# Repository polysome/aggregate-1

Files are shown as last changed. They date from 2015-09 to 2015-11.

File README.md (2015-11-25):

# aggregate-1

The aggregate-1 is a general purpose FPGA development platform for designs that require both a large fabric and high speed interconnect. The miniPCIe interface allows operation with most laptops, embedded SBCs and routers. It is particularly suited to security applications.

Hardware
========

• Xilinx Spartan 6 LX150T<br />
• 1GB DDR3<br />
• microSD card slot (bootable)<br />
• 128Mb write protected SPI flash<br />
• External frequency reference input for realtime applications.<br />
• Onboard 32.768KHz and 100MHz oscillators.<br />
• 38 pairs of 1.5V GPIO over two flex cable breakout headers ~ 7.6Gbps @ 200MHz.<br />
• Open source design including gerber files, manufacturing specifications, BOM and source list.<br />

Applications
============

• Libre SoC development. Bitstreams for RISC-V and OpenSPARC will be available<br />
• Hardware Security Module (HSM)<br />
• Authentication token<br />
• Verifiable encrypted storage with cascade blockciphers and isolated PIN entry<br />
• Cryptographic acceleration<br />
• Software defined radio<br />

Preorder
========

Preorders are available now at &nbsp; <a href="https://www.crowdsupply.com/polysome/aggregate-1">CrowdSupply</a>




Credits
=======

This project is a collaboration between [Numato Lab](http://numato.com) and Polysome Research. 

Anoop Jose<br />
Elijah Fedele<br />
Thom Lauret<br />

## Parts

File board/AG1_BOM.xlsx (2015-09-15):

Designator | Footprint | Value | Tolerance | Quantity | Manufacturer | Manufacturer Part Number | Description | Component Documentation | Supplier | Supplier Part Number | Price Break @500+ | Price Break @1000+ | MOQ @500 | MOQ @1000 | MOQ @500 Cost | MOQ @1000 Cost | Actual Required @ 500 | Actual Required @ 1000 | MOQ Surplus @500 | MOQ Surplus @1000 | MOQ Surplus $@500 | MOQ Surplus $@1000 | Digi-Reel Part Number | Digi-Reel Best Break @500 | Digi-Reel Best Break @1000 | Digi-Reel Cost @500 | Digi-Reel Cost @1000
C1, C2, C3, C4, C5, C6, C7, C8, C9, C10, C11, C12, C13, C14, C15, C16, C17, C18, C19, C20, C21, C22, C23, C25, C27, C66, C67, C68, C69, C70, C71, C79, C80,C92 | 0402 (1005 METRIC) | 0.1uF | 5% | 34 | Kemet | C0402C104J4RACTU | CAP CER 0.1UF 16V 5% X7R 0402 | http://www.kemet.com/Lists/ProductCatalog/Attachments/53/KEM_C1002_X7R_SMD.pdf | Digi-Key | 399-7761-2-ND | 0.084630 | 0.076440 | 20000 | 50000 | 1692.6 | 3822 | 17000 | 34000 | 3000 | 16000 | 253.89 | 1223.04 | 399-7761-6-ND | 0.103740 | 0.103740 | 1770.58 | 3534.16
C24, C26 | 0402 (1005 METRIC) | 15pF | 1% | 2 | Kemet | CBR04C150F1GAC | CAP CER 15PF 100V 1% NP0 0402 | http://www.kemet.com/Lists/ProductCatalog/Attachments/490/KEM_C1030_CBR_SMD.pdf | Digi-Key | 399-11249-2-ND | 0.142520 | 0.142520 | 10000 | 10000 | 1425.2 | 1425.2 | 1000 | 2000 | 9000 | 8000 | 1282.68 | 1140.16 | 399-11249-6-ND | 0.229050 | 0.198510 | 236.05 | 404.02
C28, C29, C30, C31, C32, C33, C38, C39, C40, C41, C42, C43, C49, C50, C51, C52, C53, C54, C59, C60, C61, C62, C84, C85, C86, C87, C88, C89 | 0402 (1005 METRIC) | 0.47uF | 10% | 28 | Kemet | C0402C474K9PACTU | CAP CER 0.47UF 6.3V 10% X5R 0402 | http://www.kemet.com/Lists/ProductCatalog/Attachments/19/KEM_C1006_X5R_SMD.pdf | Digi-Key | 399-4899-2-ND | 0.016150 | 0.015300 | 20000 | 30000 | 323 | 459 | 14000 | 28000 | 6000 | 2000 | 96.9 | 30.6 | 399-4899-6-ND | 0.019760 | 0.019760 | 283.64 | 560.28
C34, C35, C44, C45, C46, C55, C56, C63, C64 | 0603 (1608 METRIC) | 4.7uF | 10% | 9 | Kemet | C0603C475K9PACTU | CAP CER 4.7UF 6.3% 10% X5R 0603 | http://www.kemet.com/Lists/ProductCatalog/Attachments/19/KEM_C1006_X5R_SMD.pdf | Digi-Key | 399-3482-2-ND | 0.018000 | 0.017100 | 8000 | 12000 | 144 | 205.2 | 4500 | 9000 | 3500 | 3000 | 63 | 51.3 | 399-3482-6-ND | 0.024750 | 0.024750 | 118.375 | 229.75
C36, C37, C47, C48, C58 | 0603 (1608 METRIC) | 100uF | 20% | 5 | AVX | F980G107MMA | CAP TANT 100UF 4V 20% 0603 | http://www.avx.com/docs/Catalogs/f98.pdf | Digi-Key | F980G107MMAAVX-ND | 0.408240 | 0.408240 | 4000 | 8000 | 1632.96 | 3265.92 | 2500 | 5000 | 1500 | 3000 | 612.36 | 1224.72 | - |  |  | 2507 | 5007
C57 | 0603 (1608 METRIC) | 47uF | 20% | 1 | AVX | F980J476MMA | CAP TANT 47UF 6.3V 20% 0603 | http://www.avx.com/docs/Catalogs/f98.pdf | Digi-Key | 478-8644-2-ND | 0.185700 | 0.185700 | 4000 | 4000 | 742.8 | 742.8 | 500 | 1000 | 3500 | 3000 | 649.95 | 557.1 | 478-8644-6-ND | 0.303320 | 0.278550 | 158.66 | 285.55
C65 | C1206 | 100uF | 10% | 1 | AVX | F950J107KAAAQ2 | CAP TANT 100UF 6.3V 10% 1206 | http://www.avx.com/docs/Catalogs/f95.pdf | Digi-Key | 478-8387-2-ND | 0.354340 | 0.354340 | 2500 | 2500 | 885.85 | 885.85 | 500 | 1000 | 2000 | 1500 | 708.68 | 531.51 | 478-8387-6-ND | 0.544160 | 0.506200 | 279.08 | 513.2
C72, C73, C76, C77 | 0603 (1608 METRIC) | 10uF | 10% | 4 | TDK | C1608JB0J106K080AB | CAP CER 10UF 6.3V 10% JB 0603 | http://product.tdk.com/en/catalog/datasheets/mlcc_commercial_general_en.pdf | Digi-Key | 445-11185-2-ND | 0.076500 | 0.076500 | 4000 | 4000 | 306 | 306 | 2000 | 4000 | 2000 | 0 | 153 | 0 | 445-11185-6-ND | 0.103500 | 0.103500 | 214 | 421
C74, C75, C82 | C0805 | 10uF | 10% | 3 | Taiyo Yuden | JMK212B7106KG-T | CAP CER 10UF 6.3V 10% X7R 0805 | http://www.yuden.co.jp/productdata/catalog/en/mlcc_all_e.pdf | Digi-Key | 587-2396-2-ND | 0.048840 | 0.048840 | 3000 | 3000 | 146.52 | 146.52 | 1500 | 3000 | 1500 | 0 | 73.26 | 0 | 587-2396-6-ND | 0.056610 | 0.056610 | 91.915 | 176.83
C78, C81 | 0402 (1005 METRIC) | 10uF | 20% | 2 | TDK | C1005X5R0J106M050BC | CAP CER 10UF 6.3V 20% X5R 0402 | http://product.tdk.com/en/catalog/datasheets/mlcc_commercial_general_en.pdf | Digi-Key | 445-8920-2-ND | 0.119000 | 0.119000 | 10000 | 10000 | 1190 | 1190 | 1000 | 2000 | 9000 | 8000 | 1071 | 952 | 445-8920-6-ND | 0.191250 | 0.157250 | 198.25 | 321.5
C83, C90, C91 | 0402 (1005 METRIC) | 4.7uF | 10% | 3 | Samsung | CL05A475KQ5NRNC | CAP CER 4.7UF 6.3% 10% X5R 0402 | http://www.samsungsem.com/global/support/library/product-catalog/__icsFiles/afieldfile/2014/11/13/MLCC.pdf | Digi-Key | 1276-1481-2-ND | 0.080000 | 0.080000 | 10000 | 10000 | 800 | 800 | 1500 | 3000 | 8500 | 7000 | 680 | 560 | 1276-1481-6-ND | 0.119670 | 0.102330 | 186.505 | 313.99
C93, C94, C95, C96 | 0603 (1608 METRIC) | 10uF | 10% | 4 | TDK | C1608JB0J106K080AB | CAP CER 10UF 6.3V 10% JB 0603 | http://product.tdk.com/en/catalog/datasheets/mlcc_commercial_general_en.pdf | Digi-Key | 445-11185-2-ND | 0.076500 | 0.076500 | 4000 | 4000 | 306 | 306 | 2000 | 4000 | 2000 | 0 | 153 | 0 | 445-11185-6-ND | 0.103500 | 0.103500 | 214 | 421
C97 | 0402 (1005 METRIC) | 100pF | 1% | 1 | Kemet | CBR04C101F3GAC | CAP CER 100PF 25V 1% NP0 0402 | http://www.kemet.com/Lists/ProductCatalog/Attachments/490/KEM_C1030_CBR_SMD.pdf | Digi-Key | 399-11246-2-ND | 0.088800 | 0.088800 | 10000 | 10000 | 888 | 888 | 500 | 1000 | 9500 | 9000 | 843.6 | 799.2 | 399-11246-6-ND | 0.158520 | 0.127650 | 86.26 | 134.65
D1 | 0603 (1608 METRIC) | —— | —— | 1 | Panasonic | LNJ426W83RA | LED HI-BRIGHT AMBER USS 0603 | http://media.digikey.com/pdf/Data%20Sheets/Panasonic%20LEDs%20PDFs/LNJ426W83RA.pdf | Digi-Key | P13681DKR-ND | 0.158320 | 0.118590 | 500 | 1000 | 79.16 | 118.59 | 500 | 1000 | 0 | 0 | 0 | 0 | - |  |  | 507 | 1007
D2 | 0606 (1616 METRIC) | —— | —— | 1 | Avago | HSMF-C114 | LED CHIP RGB 1.6X1.5X0.35MM SMD | http://www.avagotech.com/docs/AV02-2451EN | Digi-Key | 516-1795-1-ND | 0.832500 | 0.720000 | 500 | 1000 | 416.25 | 720 | 500 | 1000 | 0 | 0 | 0 | 0 | 516-1795-6-ND | 0.832500 | 0.720000 | 423.25 | 727
P1, P2 | FH12-40S-0.5SH(55) | —— | —— | 2 | Hirose Electric | FH12-40S-0.5SH(55) | CONN FFC BOTTOM 40POS 0.50MM R/A | http://media.digikey.com/pdf/Data%20Sheets/Hirose%20PDFs/FH12.pdf | Digi-Key | HFJ140TR-ND | 1.694000 | 1.694000 | 2000 | 2000 | 3388 | 3388 | 1000 | 2000 | 1000 | 0 | 1694 | 0 | HFJ140DKR-ND | 1.929950 | 1.929950 | 1936.95 | 3866.9
P3 | W.FL-R-SMT-1 | —— | —— | 1 | Hirose Electric | W.FL-R-SMT-1(10) | CONN W.FL JACK STR 50 OHM SMD | http://www.hirose.co.jp/cataloge_hp/ed_WFL_20141024.pdf | Digi-Key | H9173TR-ND | 0.720000 | 0.720000 | 2000 | 2000 | 1440 | 1440 | 500 | 1000 | 1500 | 1000 | 1080 | 720 | H9173DKR-ND | 0.969400 | 0.844800 | 491.7 | 851.8
P4 | 0.4MM 14POS SMD | —— | —— | 1 | Molex | 5024261430 | CONN 0.4MM BTB RCPT 14POS SMD | http://www.molex.com/pdm_docs/sd/5024261430_sd.pdf | Digi-Key | WM9059CT-ND | 0.880440 | 0.880440 | 500 | 1000 | 440.22 | 880.44 | 500 | 1000 | 0 | 0 | 0 | 0 | WM9059DKR-ND | 0.880440 | 0.880440 | 447.22 | 887.44
P7 | MicroSD | —— | —— | 1 | Molex | 5008730816 | TFR CARD ASSY 8CKT EMBSTPPKG | http://www.molex.com/pdm_docs/sd/5008730816_sd.pdf | Digi-Key | 5008730816-ND | 1.452470 | 1.452470 | 8400 | 8400 | 12200.748 | 12200.748 | 500 | 1000 | 7900 | 7400 | 11474.513 | 10748.278 | - |  |  | 507 | 1007
R1, R2, R9, R10,R52 | 0402 (1005 METRIC) | 100R | 0.1% | 4 | Panasonic | ERA-2AEB101X | RES SMD 100 OHM 0.1% 1/16W 0402 | http://industrial.panasonic.com/lecs/www-data/pdf/AOA0000/AOA0000CE26.pdf | Digi-Key | P100DCTR-ND | 0.057020 | 0.057020 | 10000 | 10000 | 570.2 | 570.2 | 2000 | 4000 | 8000 | 6000 | 456.16 | 342.12 | P100DCDKR-ND | 0.10368 | 0.077760 | 214.36 | 318.04
R3, R4, R5, R6, R7, R8,R27, R28, R30, R33, R34, R35, R36, R39, R40, R41, R42, R43, R44, R45 | 0402 (1005 METRIC) | 4.7K | 0.1% | 20 | Panasonic | ERA-2AEB472X | RES SMD 4.7K OHM 0.1% 1/16W 0402 | http://industrial.panasonic.com/lecs/www-data/pdf/AOA0000/AOA0000CE26.pdf | Digi-Key | P4.7KDCTR-ND | 0.057020 | 0.057020 | 10000 | 20000 | 570.2 | 1140.4 | 10000 | 20000 | 0 | 0 | 0 | 0 | P4.7KDCDKR-ND | 0.077760 | 0.077760 | 784.6 | 1562.2
R11, R12,R25, R26 | 0402 (1005 METRIC) | 240R | 0.1% | 4 | Panasonic | ERA-2AEB241X | RES SMD 240 OHM 0.1% 1/16W 0402 | http://industrial.panasonic.com/lecs/www-data/pdf/AOA0000/AOA0000CE26.pdf | Digi-Key | P240DCTR-ND | 0.057020 | 0.057020 | 10000 | 10000 | 570.2 | 570.2 | 2000 | 4000 | 8000 | 6000 | 456.16 | 342.12 | P240DCDKR-ND | 0.103680 | 0.077760 | 214.36 | 318.04
R13, R19 | 0402 (1005 METRIC) | 50R | 0.1% | 2 | Vishay | FC0402E50R0BST1 | RES SMD 50 OHM 0.1% 1/20W 0402 | http://www.vishay.com/docs/60093/fcseries.pdf | Digi-Key | FC0402-50BWTR-ND | 0.910000 | 0.892500 | 1000 | 2000 | 910 | 1785 | 1000 | 2000 | 0 | 0 | 0 | 0 | FC0402-50BWDKR-ND | 1.470000 | 1.470000 | 1477 | 2947
R14, R15, R16, R17, R18, R20, R21, R22, R23, R24 | 0804, CONVEX | 49.9R | 1% | 10 | Vishay | CRA04S08349R9FTD | RES ARRAY 49.9 OHM 4 RES 0804 | http://www.vishay.com/docs/31043/cra04s.pdf | Digi-Key | CRA4S849.9ATR-ND | 0.043790 | 0.043790 | 10000 | 10000 | 437.9 | 437.9 | 5000 | 10000 | 5000 | 0 | 218.95 | 0 | CRA4S849.9ADKR-ND | 0.055790 | 0.055790 | 285.95 | 564.9
R29, R63, R64, R65, R66, R73, R75 | 0402 (1005 METRIC) | 10K | 0.1% | 7 | Panasonic | ERA-2AEB103X | RES SMD 10K OHM 0.1% 1/16W 0402 | http://industrial.panasonic.com/lecs/www-data/pdf/AOA0000/AOA0000CE26.pdf | Digi-Key | P10KDCTR-ND | 0.057020 | 0.057020 | 10000 | 10000 | 570.2 | 570.2 | 3500 | 7000 | 6500 | 3000 | 370.63 | 171.06 | P10KDCDKR-ND | 0.077760 | 0.077760 | 279.16 | 551.32
R31, R32 | 0402 (1005 METRIC) | 1K | 0.1% | 2 | Panasonic | ERA-2AEB102X | RES SMD 1K OHM 0.1% 1/16W 0402 | http://industrial.panasonic.com/lecs/www-data/pdf/AOA0000/AOA0000CE26.pdf | Digi-Key | P1.0KDCTR-ND | 0.057020 | 0.057020 | 10000 | 10000 | 570.2 | 570.2 | 1000 | 2000 | 9000 | 8000 | 513.18 | 456.16 | P1.0KDCDKR-ND | 0.103680 | 0.103680 | 110.68 | 214.36
R37, R47, R49, R50, R60, R74 | 0402 (1005 METRIC) | 100K | 0.1% | 6 | Panasonic | ERA-2AEB104X | RES SMD 100K OHM 0.1% 1/16W 0402 | http://industrial.panasonic.com/lecs/www-data/pdf/AOA0000/AOA0000CE26.pdf | Digi-Key | P100KDCTR-ND | 0.057020 | 0.057020 | 10000 | 10000 | 570.2 | 570.2 | 3000 | 6000 | 7000 | 4000 | 399.14 | 228.08 | P100KDCDKR-ND | 0.103680 | 0.077760 | 318.04 | 473.56
R38 | 0402 (1005 METRIC) | 130R | 0.1% | 1 | Panasonic | ERA-2AEB131X | RES SMD 130 OHM 0.1% 1/16W 0402 | http://industrial.panasonic.com/lecs/www-data/pdf/AOA0000/AOA0000CE26.pdf | Digi-Key | P130DCTR-ND | 0.057020 | 0.057020 | 10000 | 10000 | 570.2 | 570.2 | 500 | 1000 | 9500 | 9000 | 541.69 | 513.18 | P130DCDKR-ND | 0.138240 | 0.103680 | 76.12 | 110.68
R55, R56, R58, R67, R68, R71 | 0402 (1005 METRIC) | 2.2K | 0.1% | 7 | Panasonic | ERA-2AEB222X | RES SMD 2.2K OHM 0.1% 1/16W 0402 | http://industrial.panasonic.com/lecs/www-data/pdf/AOA0000/AOA0000CE26.pdf | Digi-Key | P2.2KDCTR-ND | 0.057020 | 0.057020 | 10000 | 10000 | 570.2 | 570.2 | 3500 | 7000 | 6500 | 3000 | 370.63 | 171.06 | P2.2KDCDKR-ND | 0.103680 | 0.077760 | 369.88 | 551.32
R46, R48 | 0402 (1005 METRIC) | 0R | —— | 2 | Panasonic | ERJ-2GE0R00X | RES SMD 0.0 OHM JUMPER 1/10W 0402 | http://industrial.panasonic.com/ww/products/resistors/chip-resistors/chip-resistors/thick-film-chip-resistors/ERJ2GE0R00X | Digi-Key | P0.0JTR-ND | 0.001980 | 0.001980 | 10000 | 10000 | 19.8 | 19.8 | 1000 | 2000 | 9000 | 8000 | 17.82 | 15.84 | P0.0JDKR-ND | 0.003840 | 0.003840 | 10.84 | 14.68
R51, R53, R54 | 0402 (1005 METRIC) | 47R | 0.1% | 3 | Panasonic | ERA-2AEB470X | RES SMD 47 OHM 0.1% 1/16W 0402 | http://industrial.panasonic.com/lecs/www-data/pdf/AOA0000/AOA0000CE26.pdf | Digi-Key | P47DCTR-ND | 0.057020 | 0.057020 | 10000 | 10000 | 570.2 | 570.2 | 1500 | 3000 | 8500 | 7000 | 484.67 | 399.14 | P47DCDKR-ND | 0.103680 | 0.103680 | 162.52 | 318.04
R57, R69 | 0402 (1005 METRIC) | 12K | 0.1% | 2 | Panasonic | ERA-2AEB123X | RES SMD 12K OHM 0.1% 1/16W 0402 | http://industrial.panasonic.com/lecs/www-data/pdf/AOA0000/AOA0000CE26.pdf | Digi-Key | P12KDCTR-ND | 0.057020 | 0.057020 | 10000 | 10000 | 570.2 | 570.2 | 1000 | 2000 | 9000 | 8000 | 513.18 | 456.16 | P12KDCDKR-ND | 0.103680 | 0.103680 | 110.68 | 214.36
R59, R70 | 0402 (1005 METRIC) | 5.1K | 0.1% | 2 | Panasonic | ERA-2AEB512X | RES SMD 5.1K OHM 0.1% 1/16W 0402 | http://industrial.panasonic.com/lecs/www-data/pdf/AOA0000/AOA0000CE26.pdf | Digi-Key | P5.1KDCTR-ND | 0.057020 | 0.057020 | 10000 | 10000 | 570.2 | 570.2 | 1000 | 2000 | 9000 | 8000 | 513.18 | 456.16 | P5.1KDCDKR-ND | 0.103680 | 0.103680 | 110.68 | 214.36
R61, R72 | 0402 (1005 METRIC) | 24K | 0.1% | 2 | Panasonic | ERA-2AEB243X | RES SMD 24K OHM 0.1% 1/16W 0402 | http://industrial.panasonic.com/lecs/www-data/pdf/AOA0000/AOA0000CE26.pdf | Digi-Key | P24KDCTR-ND | 0.057020 | 0.057020 | 10000 | 10000 | 570.2 | 570.2 | 1000 | 2000 | 9000 | 8000 | 513.18 | 456.16 | P24KDCDKR-ND | 0.103680 | 0.103680 | 110.68 | 214.36
U1, U2 | 96-FBGA | —— | —— | 2 | Micron | MT41J256M16HA-093G:E | IC DDR3 SDRAM 4GBIT FBGA | http://www.micron.com/~/media/Documents/Products/Data%20Sheet/DRAM/DDR3/4Gb_DDR3_SDRAM.pdf | Avnet | MT41J256M16HA-093G:E | 3.780000 | 3.780000 | 2000 | 2000 | 7560 | 7560 | 1000 | 2000 | 1000 | 0 | 3780 | 0 |  |  |  | 1007 | 2007
U3 {A} | 484-FBGA | —— | —— | 1 | Xilinx | XC6SLX100T-3FGG484I | IC FPGA 296 I/O 484FBGA | http://www.xilinx.com/support/documentation/data_sheets/ds160.pdf | Avnet | XC6SLX100T-3FGG484I | 98.150000 | 91.600000 | 500 | 1000 | 49075 | 91600 | 500 | 1000 | 0 | 0 | 0 | 0 |  |  |  | 507 | 1007
U3 {B} | 484-FBGA | —— | —— | 1 | Xilinx | XC6SLX150T-3FGG484I | IC FPGA 296 I/O 484FBGA | http://www.xilinx.com/support/documentation/data_sheets/ds160.pdf | Avnet | XC6SLX150T-3FGG484I | 137.000000 | 128.000000 | 500 | 1000 | 68500 | 128000 | 500 | 1000 | 0 | 0 | 0 | 0 |  |  |  | 507 | 1007
U4 | SOIC-8 | —— | —— | 1 | Micron | N25Q128A13EF840E | IC FLASH 128MBIT 108MHZ 8SO | http://www.micron.com/~/media/Documents/Products/Data%20Sheet/NOR%20Flash/Serial%20NOR/N25Q/n25q_128mb_3v_65nm.pdf | Digi-Key | 557-1561-ND | 1.390200 | 1.330560 | 500 | 1000 | 695.1 | 1330.56 | 500 | 1000 | 0 | 0 | 0 | 0 | - |  |  | 507 | 1007
U5 | 4-SMD NO LEAD | —— | —— | 1 | Abracon | ASEM1-100.000MHZ-LC-T | OSC MEMS 100.000MHZ CMOS SMD | http://www.abracon.com/Oscillators/ASEM.pdf | Digi-Key | 535-9777-1-ND | 1.269600 | 1.269600 | 500 | 1000 | 634.8 | 1269.6 | 500 | 1000 | 0 | 0 | 0 | 0 | 535-9777-6-ND | 1.269600 | 1.269600 | 641.8 | 1276.6
U6 | 4-SMD NO LEAD | —— | —— | 1 | CTS-Frequency Controls | TC25L5I32K7680 | OSC XO 32.768KHZ CMOS SMD | http://media.digikey.com/pdf/Data%20Sheets/CTS%20Corporation%20PDFs/Model%20TC25.pdf | Digi-Key | CTX1183TR-ND | 1.092000 | 1.092000 | 1000 | 1000 | 1092 | 1092 | 500 | 1000 | 500 | 0 | 546 | 0 | CTX1183DKR-ND | 1.327200 | 1.327200 | 670.6 | 1334.2
U7, U9 | 10-UDFN | —— | —— | 2 | Diodes Incorporated | AP7176BFN-7 | IC REG LDO ADJ 3A 10-DFN | http://diodes.com/datasheets/AP7176B.pdf | Digi-Key | AP7176BFN-7DICT-ND | 0.426250 | 0.426250 | 1000 | 2000 | 426.25 | 852.5 | 1000 | 2000 | 0 | 0 | 0 | 0 | AP7176BFN-7DIDKR-ND | 0.426250 | 0.426250 | 433.25 | 859.5
U8 | 10-VSON | —— | —— | 1 | Texas Instruments | TPS51200DRCR | IC CONV DDR DDR2 DDR3 10SON | http://www.ti.com/lit/ds/symlink/tps51200.pdf | Digi-Key | 296-26978-1-ND | 1.180000 | 0.844000 | 500 | 1000 | 590 | 844 | 500 | 1000 | 0 | 0 | 0 | 0 | 296-26978-6-ND | 1.180000 | 0.844000 | 597 | 851
JTAG adapter P1 | .4MM 14 POS SMD | —— | —— | 1 | Panasonic | AXE614124 | CONN HEADER .4MM 14 POS SMD | http://www3.panasonic.biz/ac/e_download/control/connector/base-fpc/catalog/con_eng_a4s.pdf | Digi-Key | 255-3200-2-ND | 0.884500 | 0.884500 | 1000 | 1000 | 884.5 | 884.5 | 500 | 1000 | 500 | 0 | 442.25 | 0 |  |  |  | 507 | 1007
JTAG adapter P2 | 2MM 14 POS THROUGH HOLE | —— | —— | 1 | Molex | 877581416 | CONN HEADER 14POS 2MM VERT GOLD | http://www.molex.com/pdm_docs/sd/877581416_sd.pdf | Digi-Key | WM18838-ND | 0.566820 | 0.503840 | 500 | 1000 | 283.41 | 503.84 | 500 | 1000 | 0 | 0 | 0 | 0 |  |  |  | 507 | 1007

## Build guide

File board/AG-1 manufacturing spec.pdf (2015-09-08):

### AG-1 {A,B} manufacturing specification

Material: Rogers 3003
Glass weave style: 3313 MS
Board thickness: 1.00 ± 0.10 mm (recommend 0.9mm)
*Card thickness applies across tabs and includes plating and/or metallization. Dimensions: 50.95mm x 30mm – follow exact requirements of miniPCIe spec. Layers: 8
Copper: 1oz
Surface finishing: ENIG Ni: 6um Au: 0.1um
Solder mask: white
Silkscreen: bright orange color
Request golden finger miniPCIe contacts Ni: 2um Au: 1um Edge bevel: 0.25mm, 45-degrees, both sides.

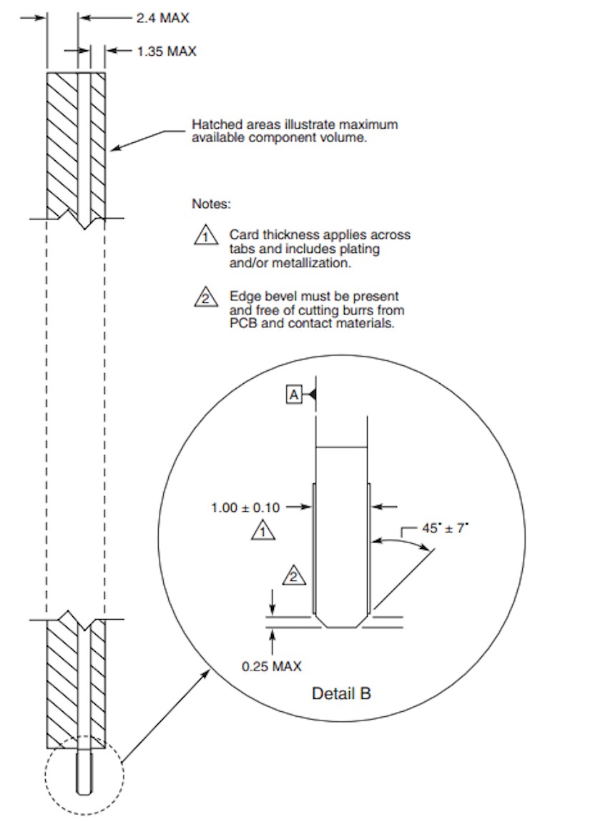
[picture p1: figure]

Layer stack up;

PolysomeCrypto01.GTL
PolysomeCrypto01.G1
PolysomeCrypto01.G2
PolysomeCrypto01.G3
PolysomeCrypto01.G4
PolysomeCrypto01.G5
PolysomeCrypto01.G6
PolysomeCrypto01.GBL

Impedance matching at 50R on all the 5 mil traces for;

PolysomeCrypto01.GTL
PolysomeCrypto01.G3
PolysomeCrypto01.G5
PolysomeCrypto01.GBL

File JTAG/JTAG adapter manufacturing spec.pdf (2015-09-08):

### AG-1 JTAG adapter manufacturing specification

Material: FR4 or IPC 6013 Type 2 Board thickness: 1mm
PCB size: 24mm*6.5mm
Layers: 2
Copper: 1oz
Surface finishing: lead free HASL Solder mask: white
Silkscreen: bright orange color

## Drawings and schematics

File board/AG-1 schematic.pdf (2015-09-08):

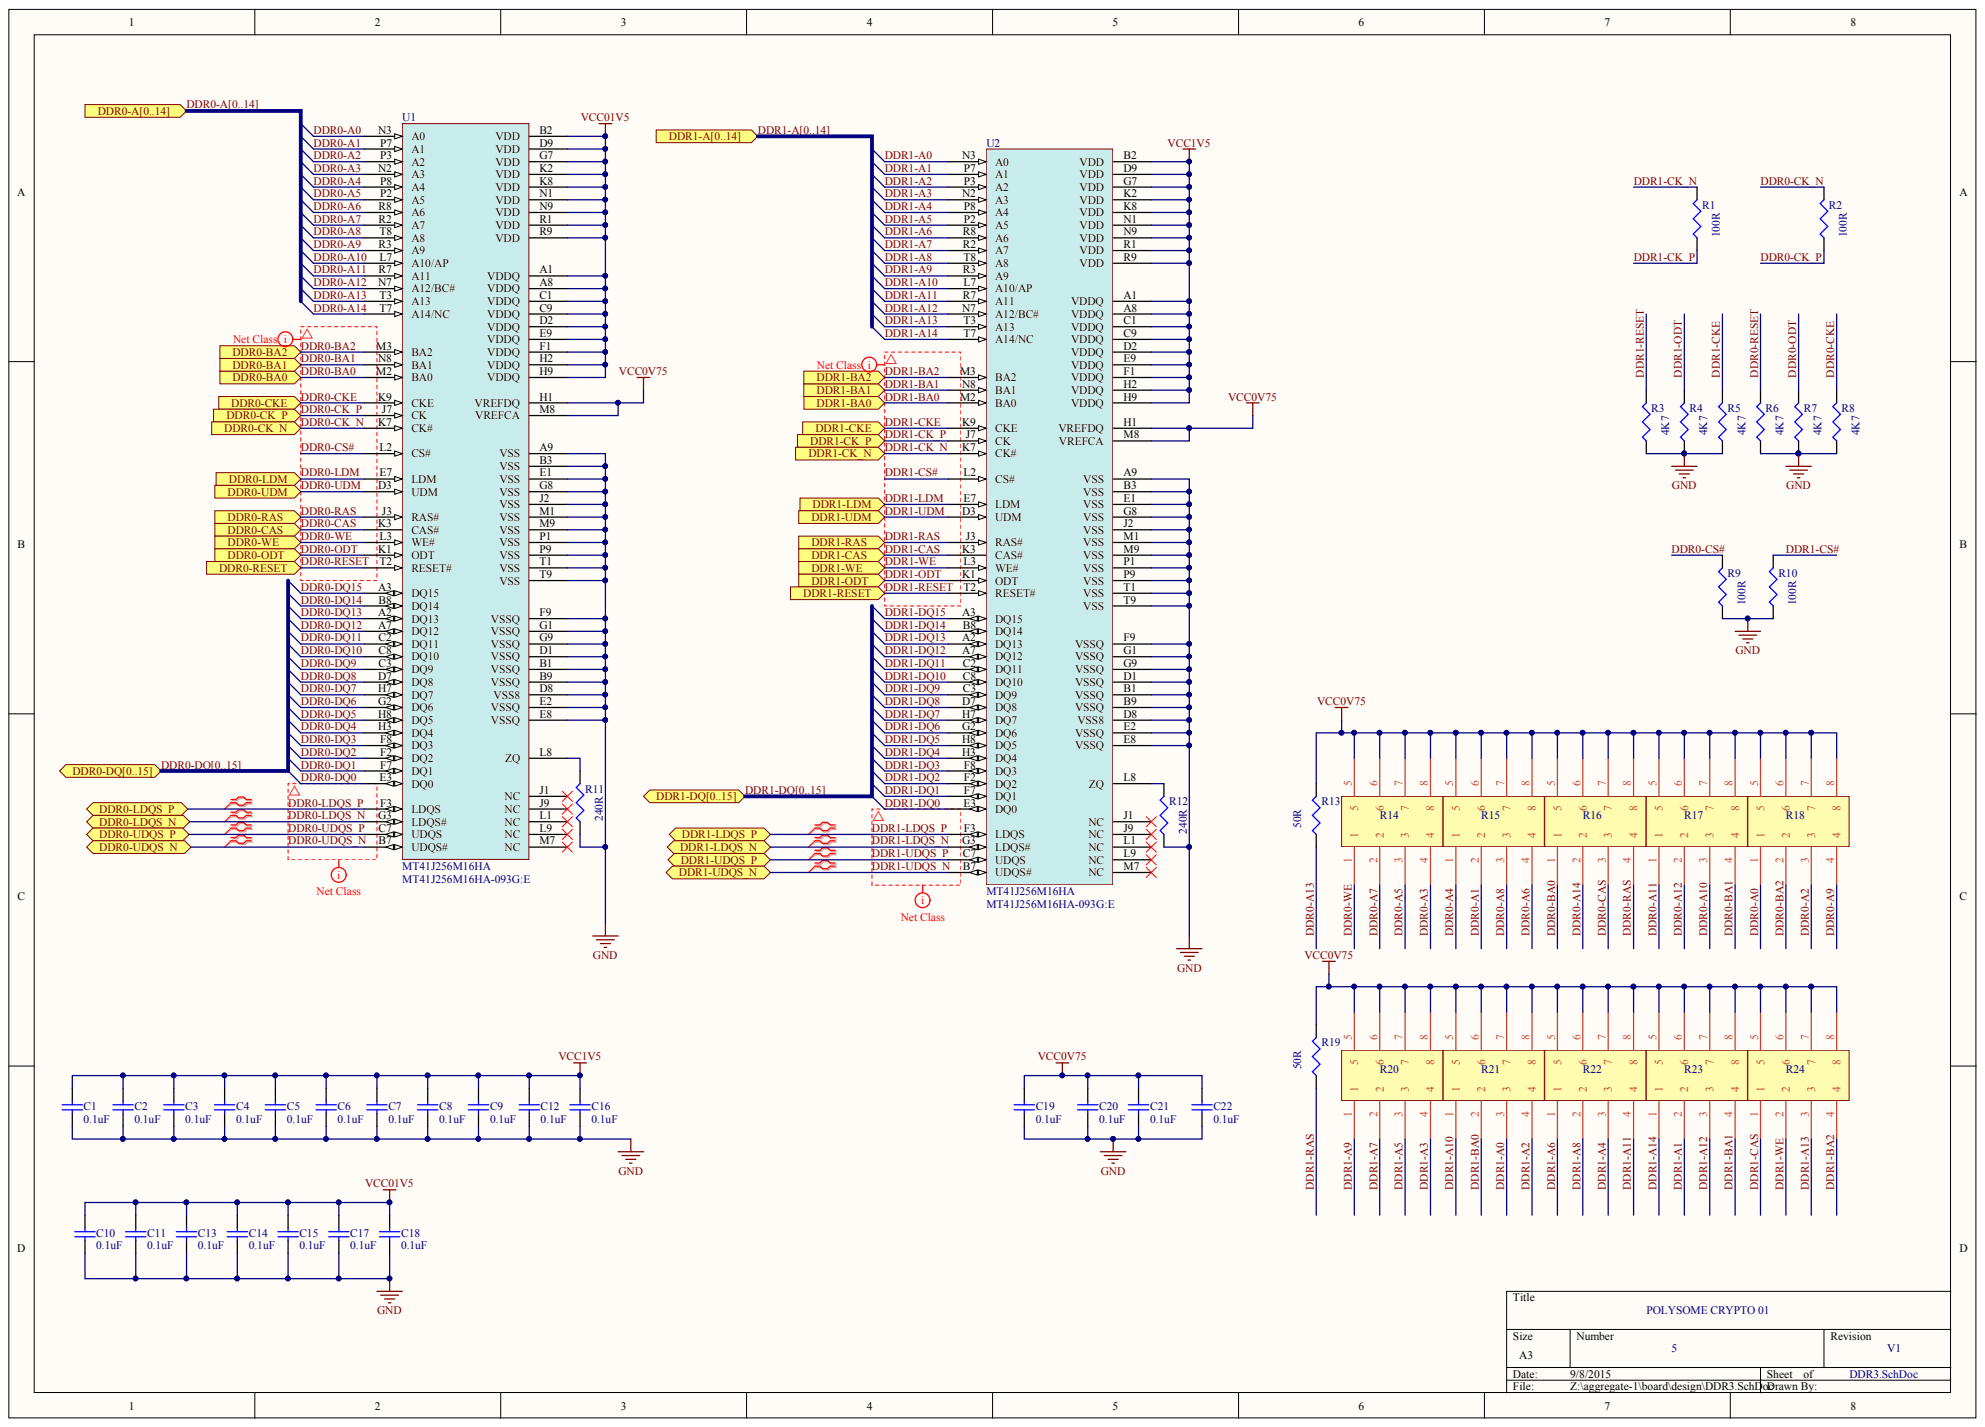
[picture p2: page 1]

DDR1-BA0 | BA0 M2

DDR0-RAS | RAS# J3

DDR1-UDM

DDR0-UDQS_P | UDQS C7
DDR0-UDQS_N | UDQS# B7

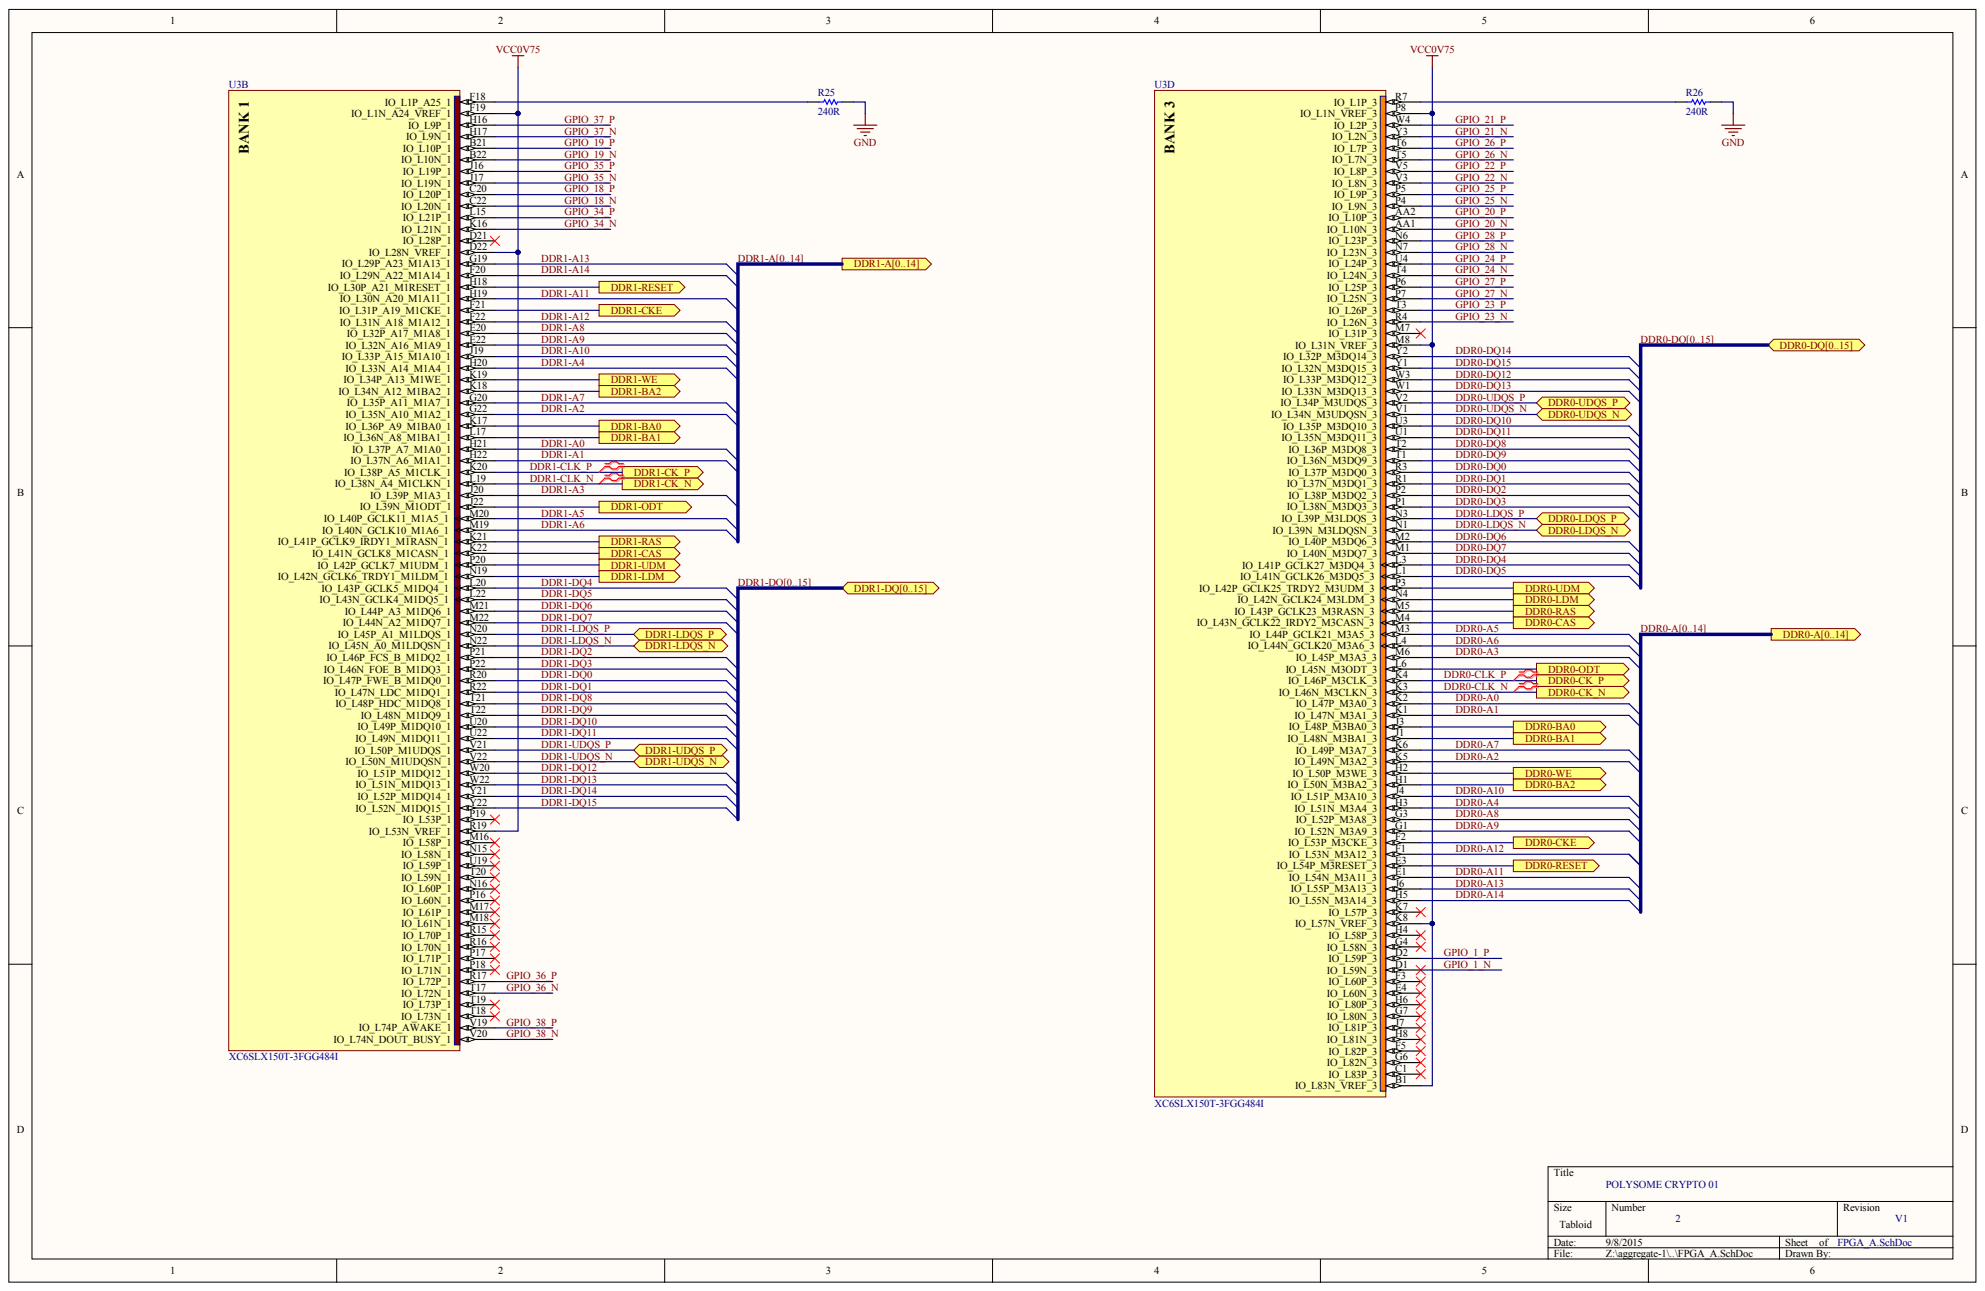
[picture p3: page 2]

T abloid | e r 2 | Re visio n V1

Date : 9/8/2 0 1 5 | S h e et o f F PGA_A.S c hDo c
File : Z:\a g g r e g ate -1\..\F PGA_A.S c hDo c | Dr awn By :

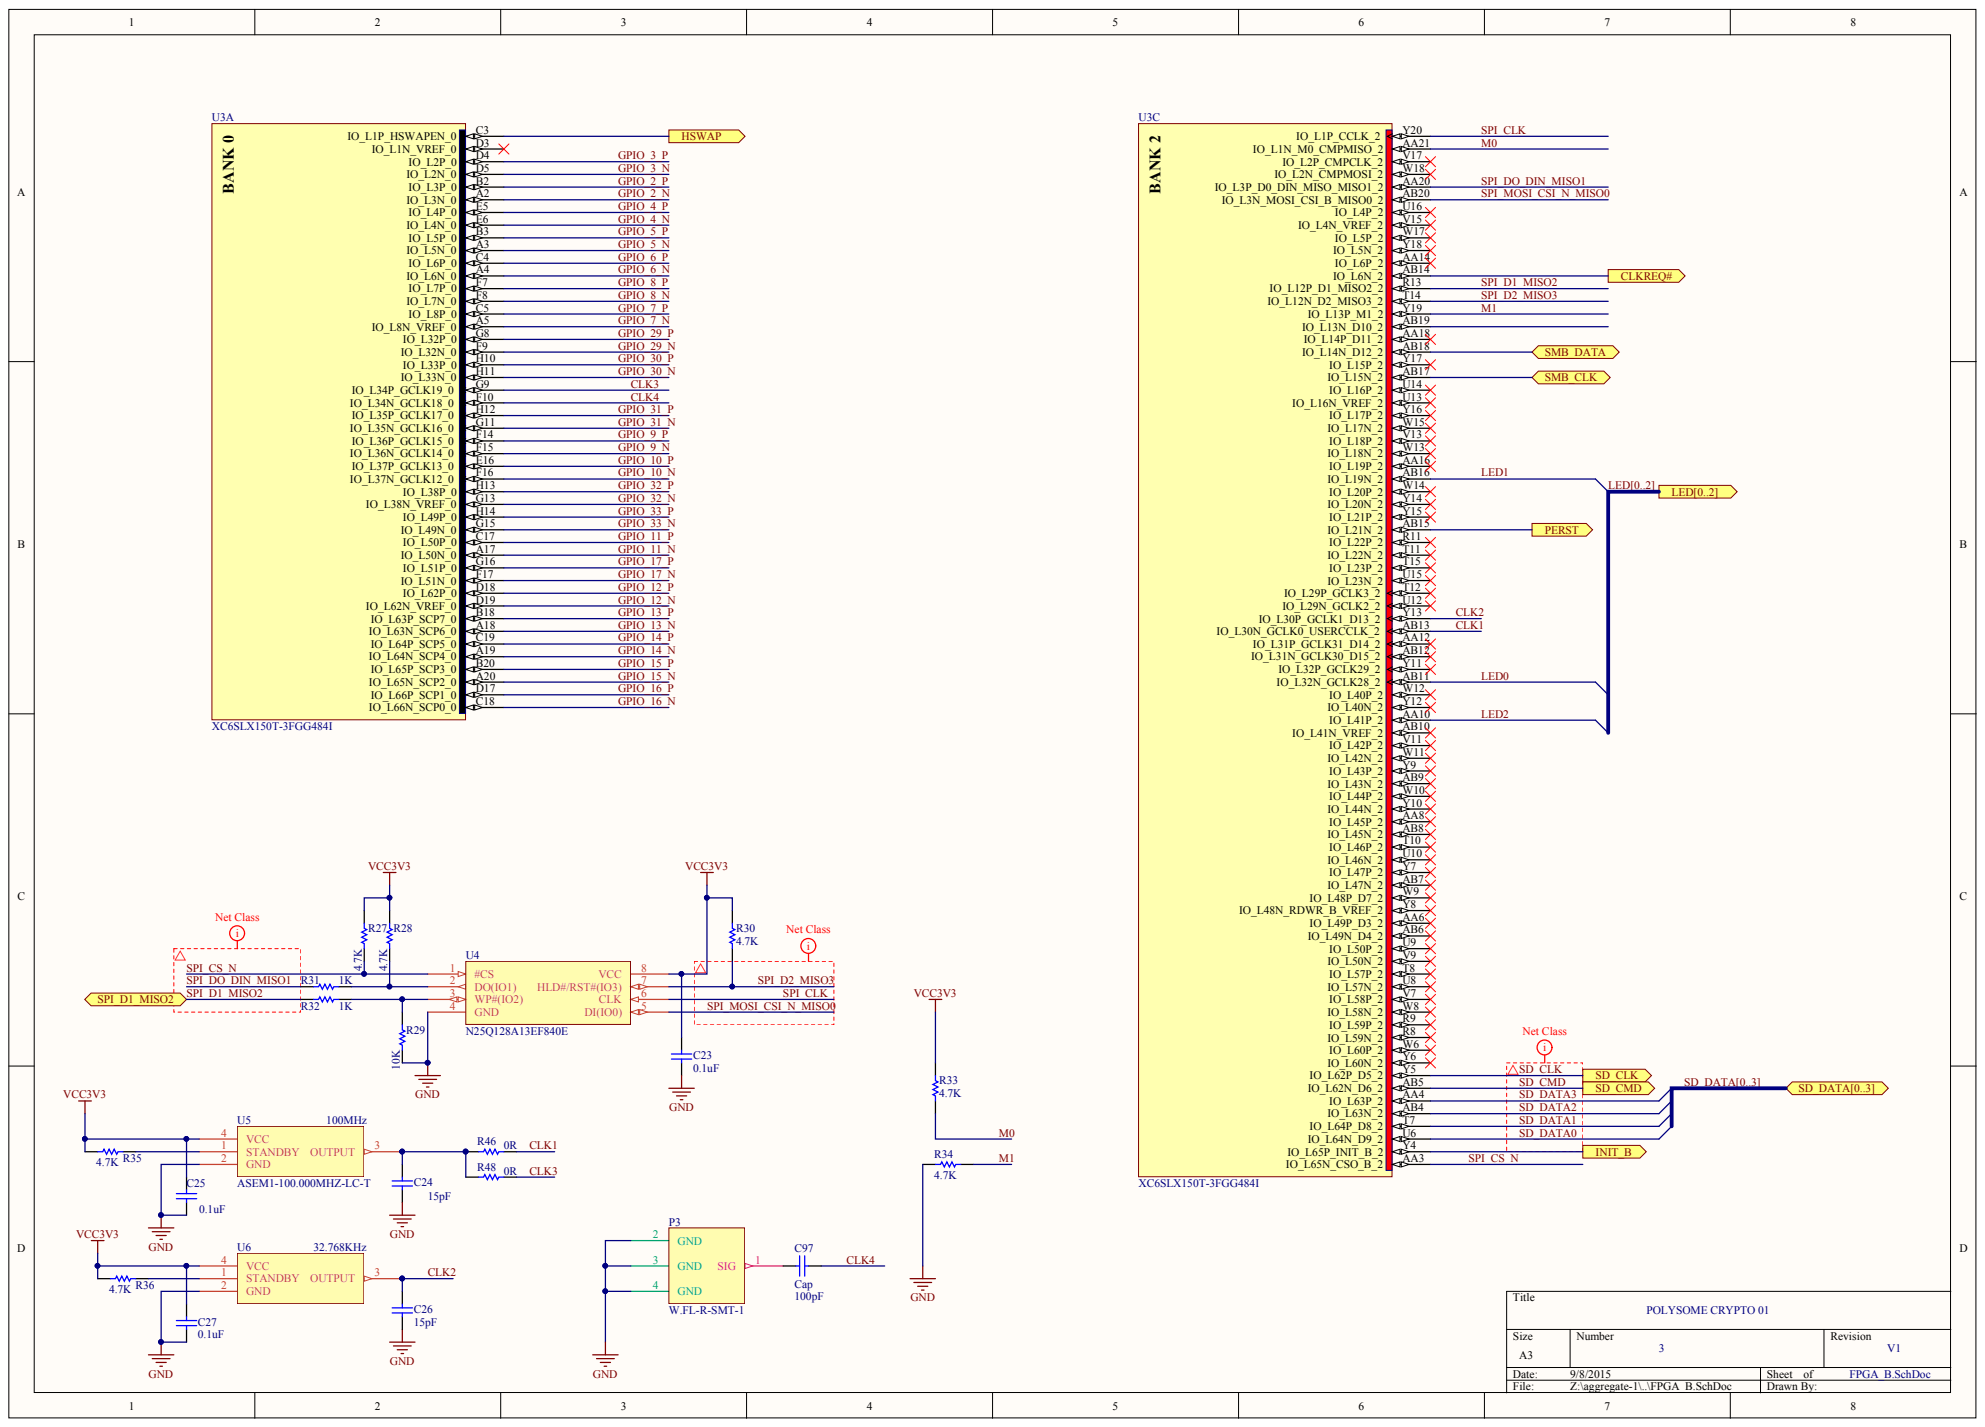
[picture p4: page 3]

5 CLK 6 | SPI_CLK

SPI_MOSI_CSI_N_MISO | 0

AB5
A A 4 | SD_D ATA 3
AB4 | SD_D ATA 2

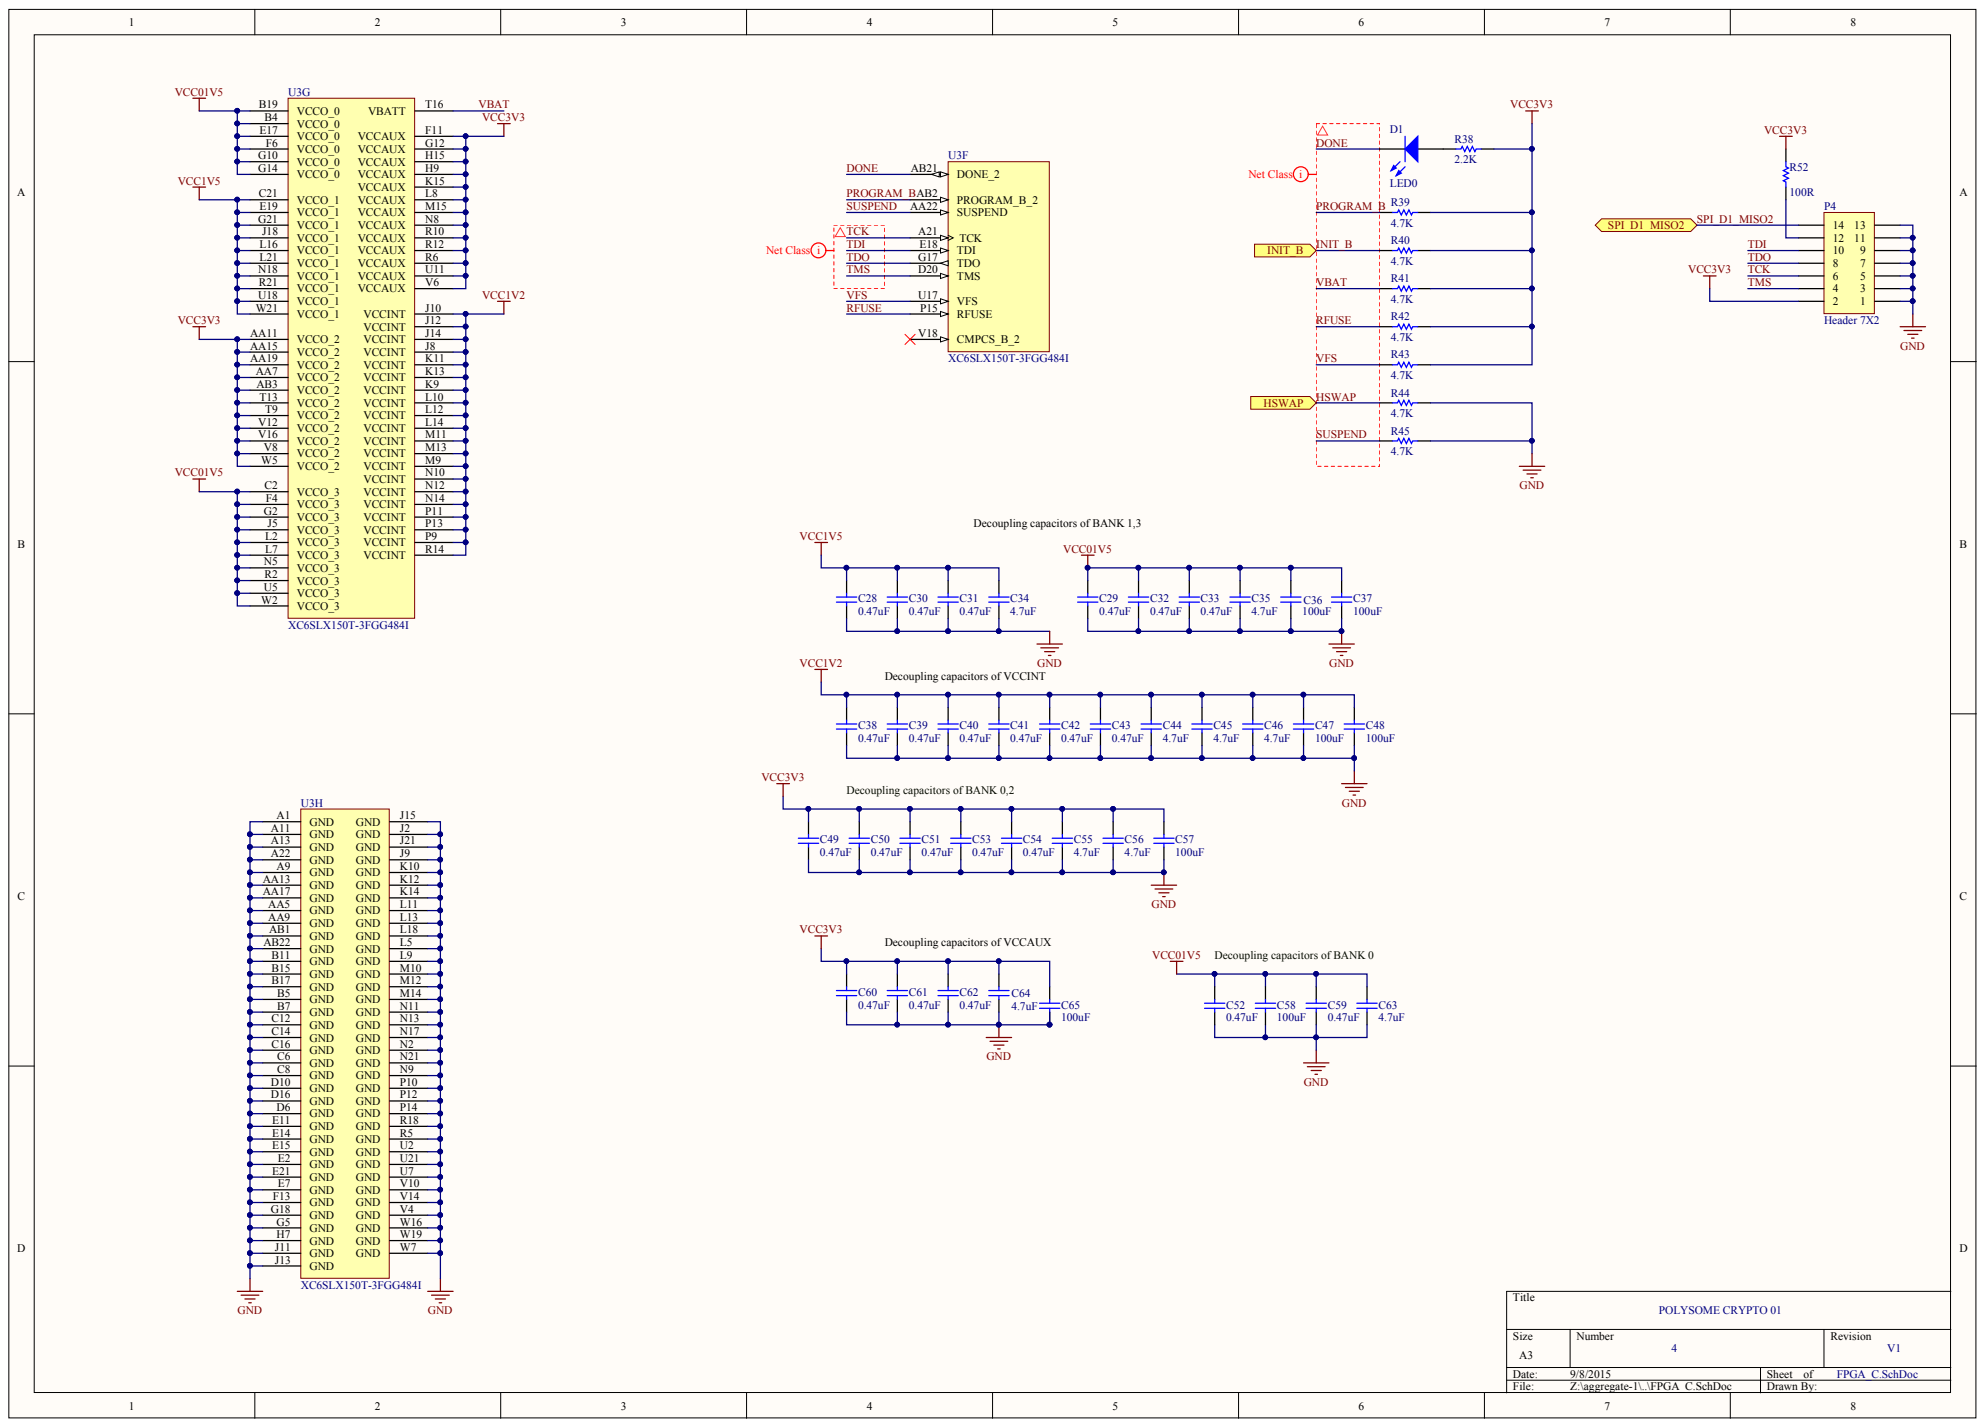
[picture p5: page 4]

VCCO_2 AA15
VCCO_2 AA19
VCCO_2 AA7
VCCO_2 AB3
VCCO_2 T13
VCCO_2 T9
VCCO_2 V12
VCCO_2 V16
VCCO_2 V8
VCCO_2 W5

VCCO_3 F4
VCCO_3 G2
VCCO_3 J5
VCCO_3 L2
VCCO_3 L7
VCCO_3 N5
VCCO_3 R2
VCCO_3 U5

Decoupling capacitors of BANK 1,3

Decoupling capacitors of VCCINT

Decoupling capacitors of BANK 0,2

GND A11
GND A13
GND A22
GND A9
GND AA13
GND AA17
GND AA5
GND AA9
GND AB1

Decoupling capacitors of VCCAUX

Decoupling capacitors of BANK 0

GND B15
GND B17
GND B5
GND B7
GND C12
GND C14
GND C16
GND C6
GND C8

GND D16
GND D6
GND E11
GND E14
GND E15
GND E2
GND E21
GND E7
GND F13
GND G18
GND G5

GND J11

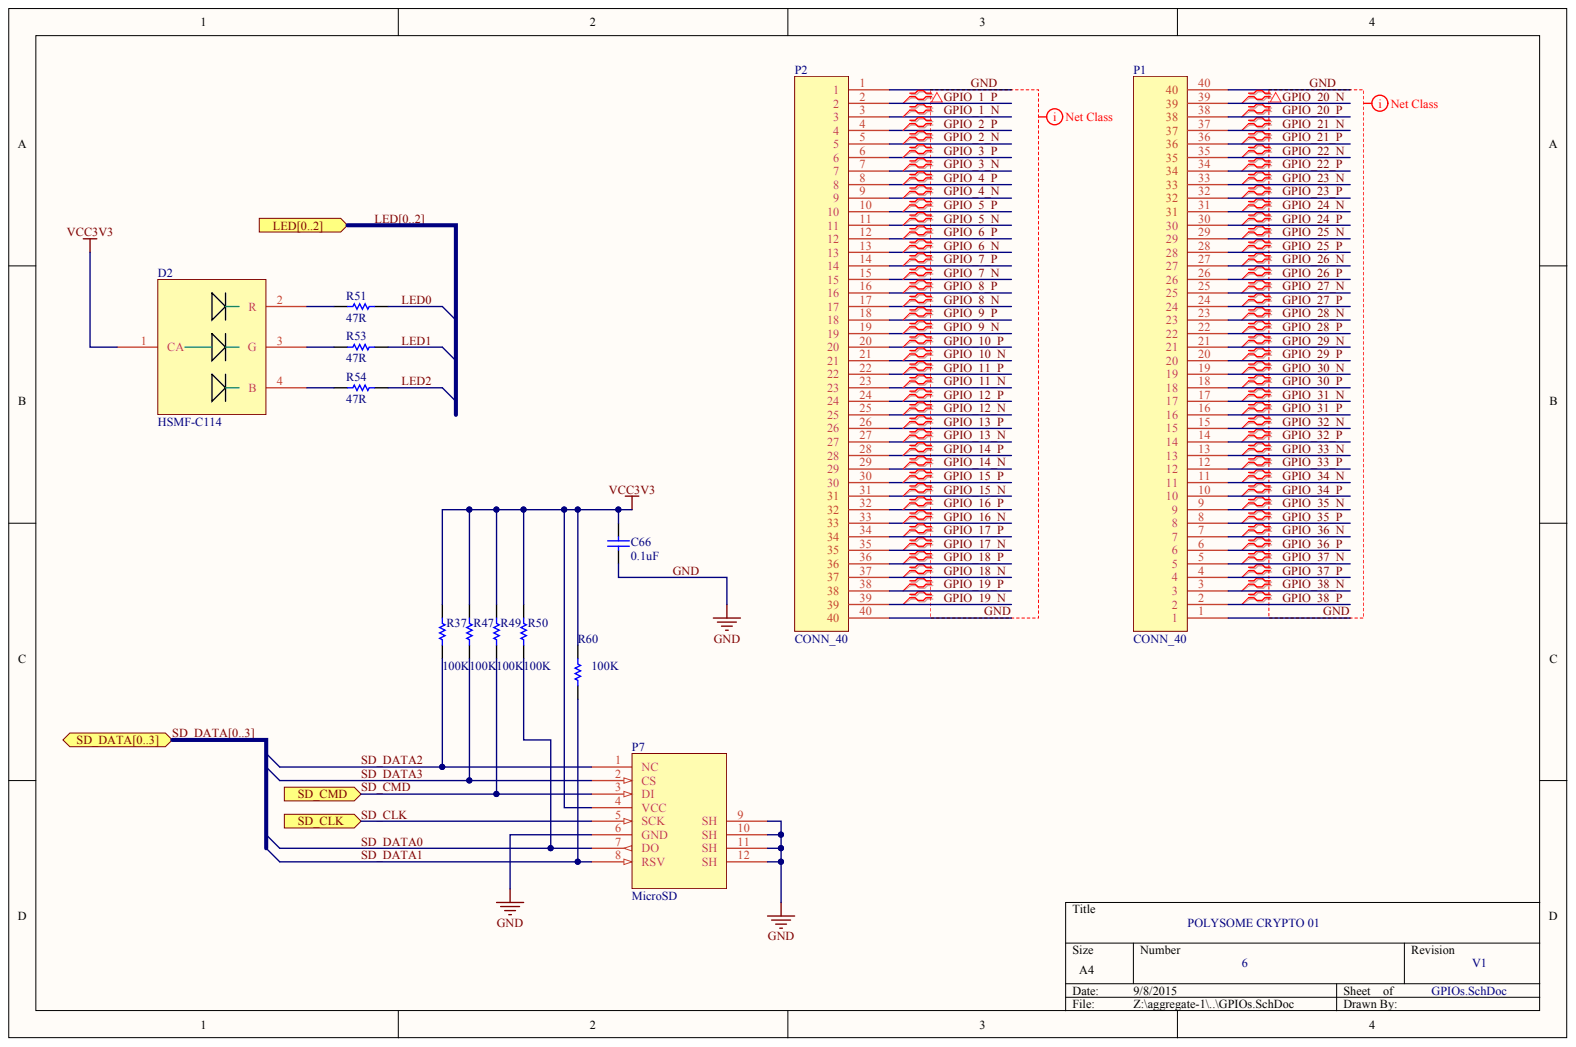
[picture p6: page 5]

Size A4 | Number | Revision

Date: 9/8/2015 | Sheet of GPIOs.SchDoc
File: Z:\aggregate-1\..\GPIOs.SchDoc | Drawn By:

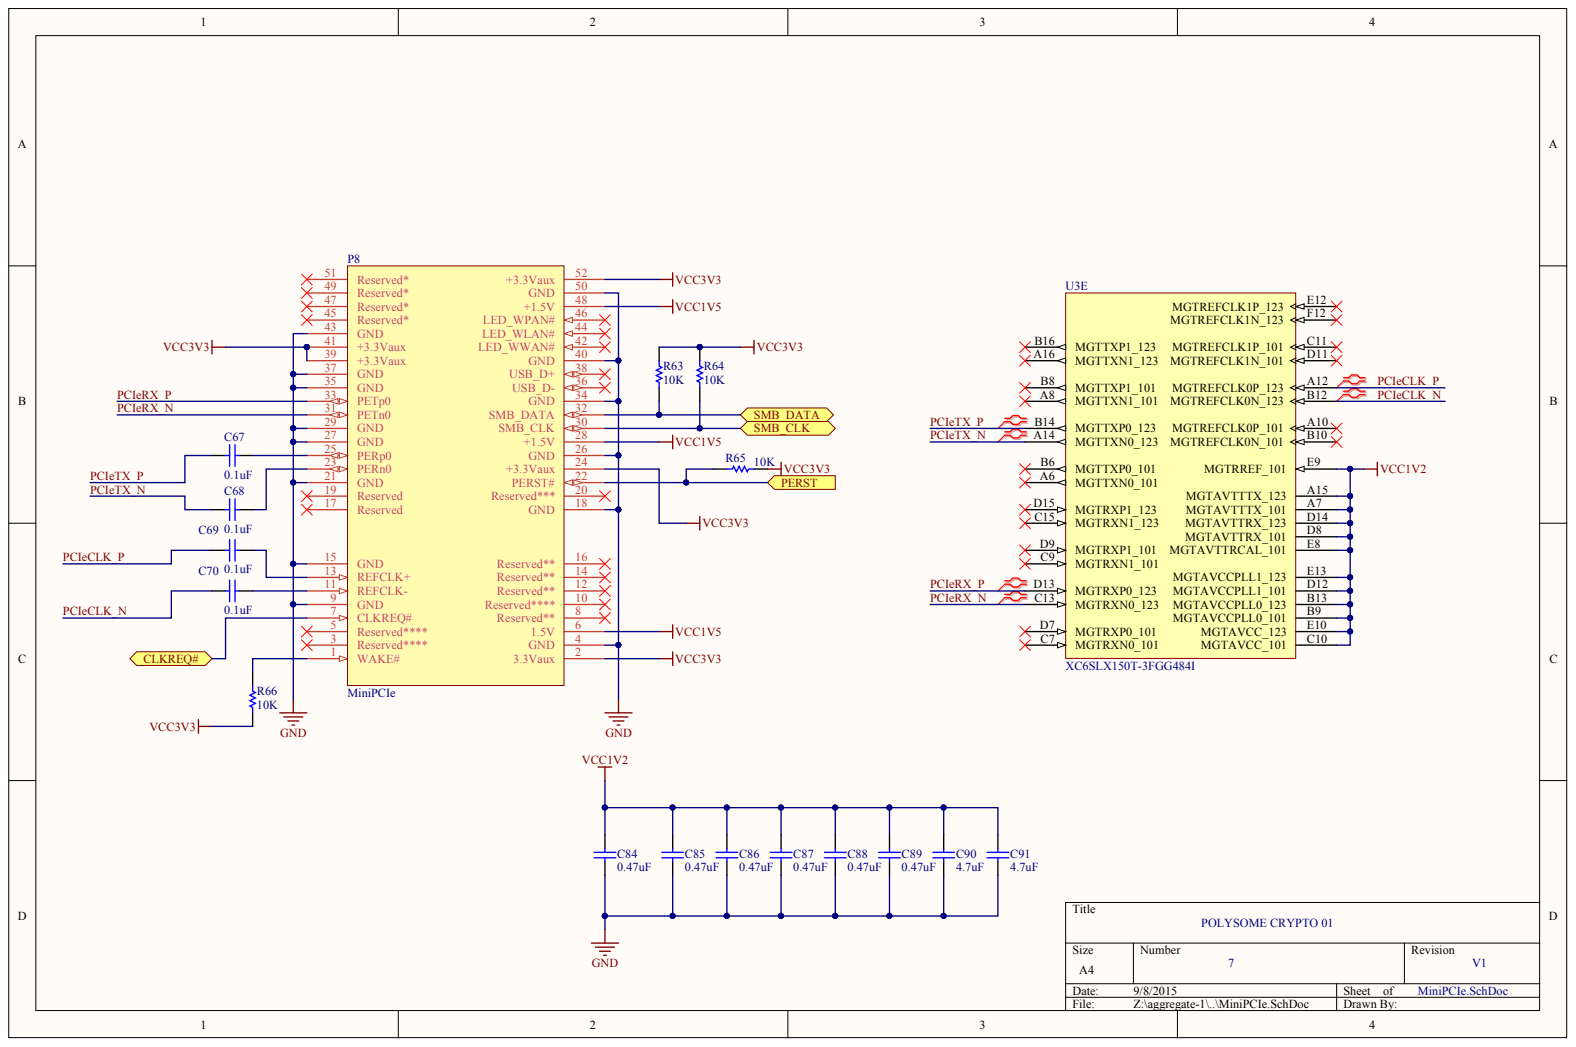
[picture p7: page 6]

PCIeCLK_P

REFCLK+ 13

Size A4 | Number 7 | Revision V1

Date: 9/8/2015 | Sheet of MiniPCIe.SchDoc
File: Z:\aggregate-1\..\MiniPCIe.SchDoc | Drawn By:

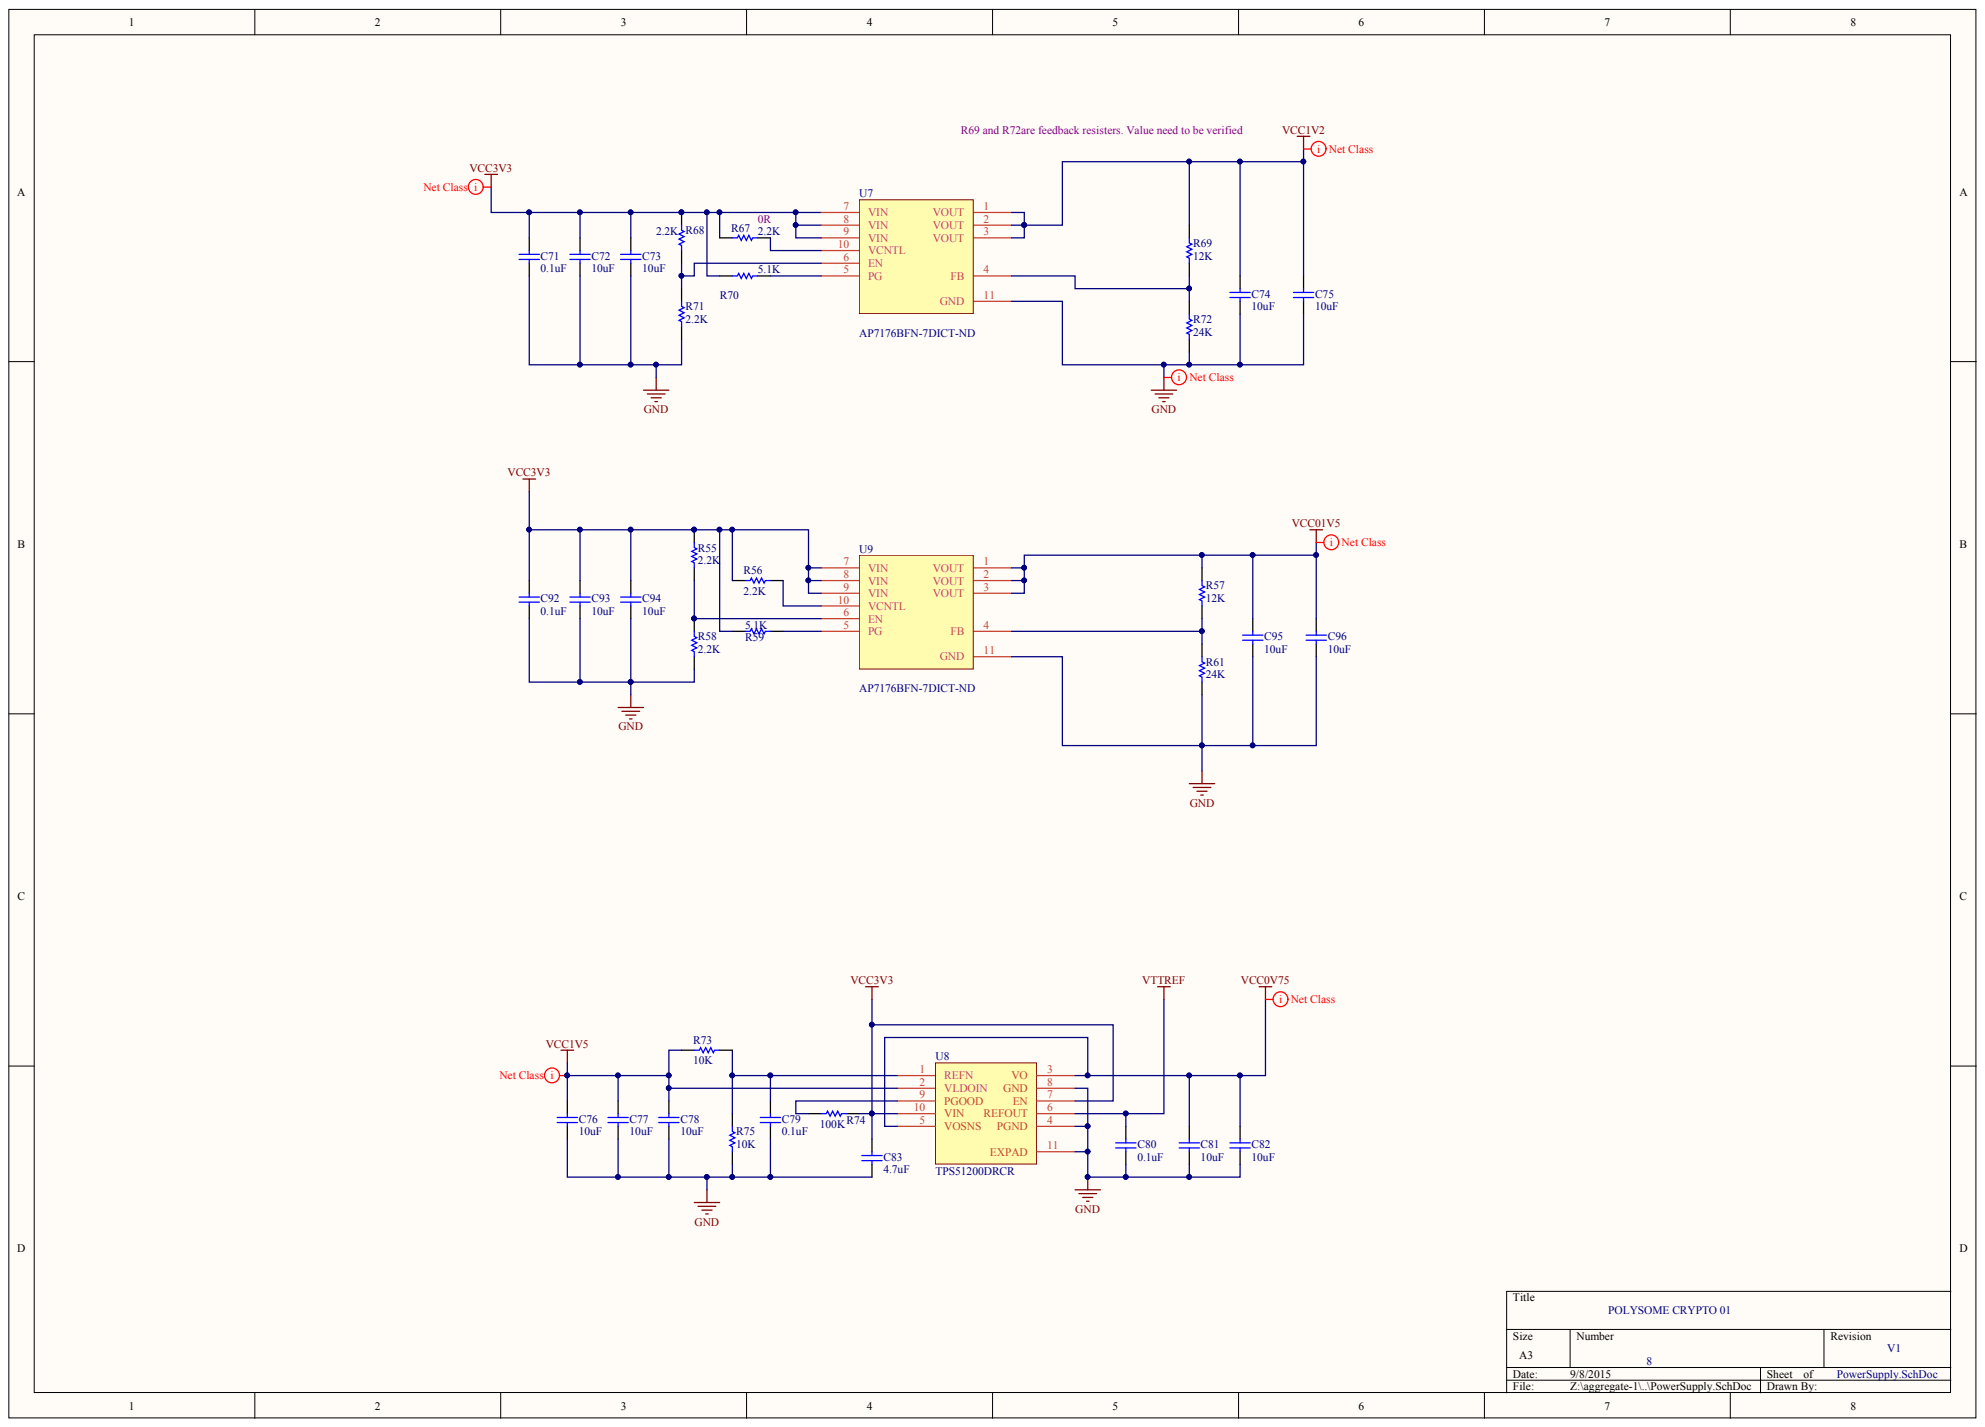
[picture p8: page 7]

R69 and R72are feedback resisters. Value need to be verified

VIN 9

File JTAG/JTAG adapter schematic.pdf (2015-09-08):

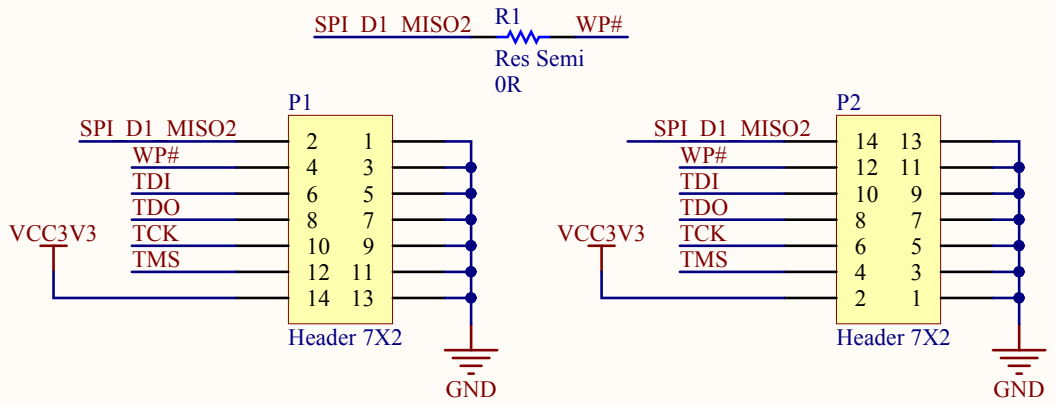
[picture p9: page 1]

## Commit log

2015-07-13 beta release
    [Crpto01JTAG.GBL, Crpto01JTAG.GBO, Crpto01JTAG.GBP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]
2015-09-08 added schematics in PDF
2015-09-09 added AG-1 BOM
    [AG1A_BOM_public.xlsx, AG1B_BOM_public.xlsx]
2015-09-11 AG-1 BOM update
    [AG1A_BOM_public.xlsx, AG1B_BOM_public.xlsx, AG1_BOM_public.xlsx]
